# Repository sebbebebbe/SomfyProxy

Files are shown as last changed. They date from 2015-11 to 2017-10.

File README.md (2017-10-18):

SomfyProxy

This is a project for controlling your Somfy blinds with a Tellstick .NET.

You are going to need:
- Raspberry Pi with node.js
- Arduino with a 433Mhz reciever module

There is a more detailed information about the circuitry in the fritzing file.

Cable to Somfy remote

1(redish color): 3,3V
2:GND
3:Stop
4:Up
5:Down
6:Select
7: CH1
8: CH2
9: CH3
10:CH4

Pins on Raspberry Pi:

function	PhysicalPIN	wPi
up		18		1
down		24		5
stop		14		15
select ch	23		4

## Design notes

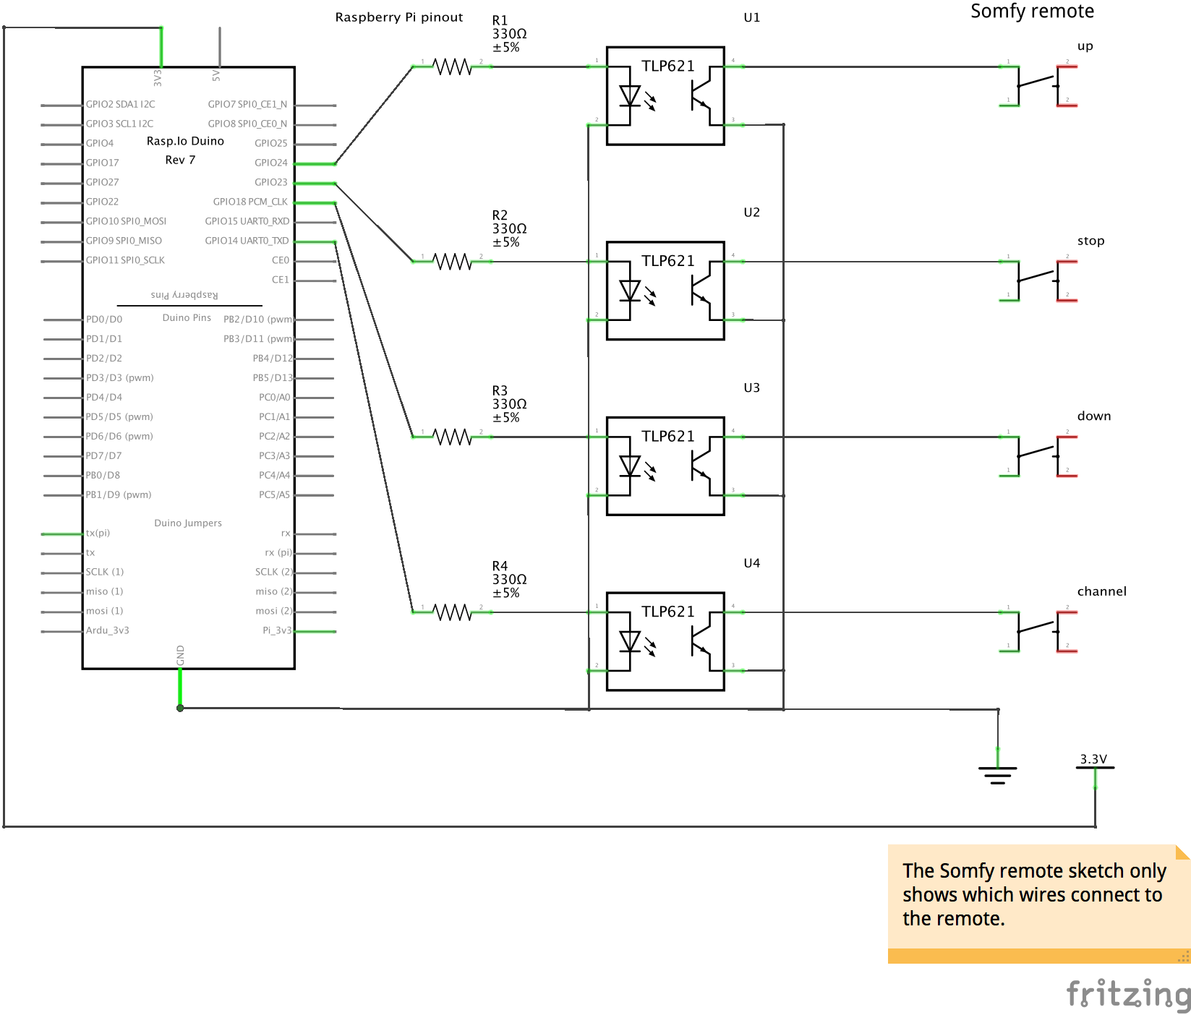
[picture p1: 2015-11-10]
SomfyProxy schematics.png

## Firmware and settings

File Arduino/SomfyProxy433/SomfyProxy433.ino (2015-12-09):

/*
SomfyProxy433

Inspired from examples @ http://code.google.com/p/rc-switch/

 DATA PIN needs to be connected to Digital input #3
 VCC PIN into 5V on Arduino
 GND PIN into ground on same side as 5V VCC
 */

#include <RCSwitch.h>
RCSwitch mySwitch = RCSwitch();

#define DATA_PIN 3

void setup() {

 pinMode(DATA_PIN, INPUT);
 
 Serial.begin(9600);
 mySwitch.enableReceive(1);  // Receiver on interrupt 1 => that is pin D3
 Serial.println("SomfyProxy433 started");
}

static unsigned long count = 0;

void loop() {
 
 if (mySwitch.available()) {
   
   int value = mySwitch.getReceivedValue();
   
   if (value == 0) {
     Serial.print("Unknown encoding");
   } 
   else {
     outputPayload(mySwitch.getReceivedValue(), mySwitch.getReceivedBitlength(), mySwitch.getReceivedDelay(), mySwitch.getReceivedRawdata(),mySwitch.getReceivedProtocol());
   }
   
   mySwitch.resetAvailable();    
   count = 0;
 }
}

void outputPayload(unsigned long decimal, unsigned int length, unsigned int delay, unsigned int* raw, unsigned int protocol) {

  if (decimal == 0) {
    Serial.print("Unknown encoding.");
  } else {
    Serial.print("payload;");
    char* b = dec2binWzerofill(decimal, length);
    //Decimal value
    Serial.print(decimal);
    Serial.print(";");
    //bitlength
    Serial.print( length );
    Serial.print(";");
    //binary
    Serial.print( b );
    Serial.print(";");
    //tri-state
    Serial.print( bin2tristate( b) );
    Serial.print(";");
    //pulse length microseconds
    Serial.print(delay);
    Serial.print(";");
    //protocol
    Serial.println(protocol);
  }
  
  Serial.print("Raw data: ");
  for (int i=0; i<= length*2; i++) {
    Serial.print(raw[i]);
    Serial.print(",");
  }
  Serial.println();
  Serial.println();
}


char* bin2tristate(char* bin) {
  char returnValue[50];
  int pos = 0;
  int pos2 = 0;
  while (bin[pos]!='\0' && bin[pos+1]!='\0') {
    if (bin[pos]=='0' && bin[pos+1]=='0') {
      returnValue[pos2] = '0';
    } else if (bin[pos]=='1' && bin[pos+1]=='1') {
      returnValue[pos2] = '1';
    } else if (bin[pos]=='0' && bin[pos+1]=='1') {
      returnValue[pos2] = 'F';
    } else {
      return "not applicable";
    }
    pos = pos+2;
    pos2++;
  }
  returnValue[pos2] = '\0';
  return returnValue;
}

char * dec2binWzerofill(unsigned long Dec, unsigned int bitLength){
  static char bin[64]; 
  unsigned int i=0;

  while (Dec > 0) {
    bin[32+i++] = (Dec & 1 > 0) ? '1' : '0';
    Dec = Dec >> 1;
  }

  for (unsigned int j = 0; j< bitLength; j++) {
    if (j >= bitLength - i) {
      bin[j] = bin[ 31 + i - (j - (bitLength - i)) ];
    }else {
      bin[j] = '0';
    }
  }
  bin[bitLength] = '\0';
  
  return bin;
}

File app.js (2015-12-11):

var express = require('express');
var app = express();
var serialport = require("serialport");
var SerialPort = serialport.SerialPort;

var sleep = require('sleep');

var Gpio = require('onoff').Gpio,
  upButton = new Gpio(18, 'out'),
  downButton = new Gpio(24, 'out'),
  stopButton = new Gpio(14, 'out'),
  selectButton = new Gpio(23, 'out')

var standardButtonPress = 60000; //microseconds

var serialPort = new SerialPort("/dev/ttyUSB1", {
	baudrate: 9600,
	parser: serialport.parsers.readline("\n")
});

serialPort.on("open", function () {
	console.log('serial port open');
	serialPort.on('data', function (data) {
		console.log(data);
		var parameters = data.split(';')

		//these values are based on what i get from my Tellstick
		if(parameters[1] == '192')
		{
			up();
		}

		if(parameters[1] == '3')
		{
			down();
		}

		if(parameters[1] == '48')
		{
			stop();
		}

	});
});

app.get('/', function(req, res) {
  	res.type('text/plain');
  	res.send('');
});

app.post('/up', function(req, res) {
	res.type('text/plain');
  	res.send('going up');

	up();
});

app.post('/down', function(req, res) {
  	res.type('text/plain');
  	res.send('going down');

	down();

});

app.post('/stop', function(req, res) {
  	res.type('text/plain');
  	res.send('stopping');

	stop();

});

app.post('/select', function(req, res) {
  	res.type('text/plain');
  	res.send('changed channel');

	selectChannel();
});

function up() {
	upButton.writeSync(1);
	sleep.usleep(standardButtonPress);
	upButton.writeSync(0);
}

function stop() {
	stopButton.writeSync(1);
	sleep.usleep(standardButtonPress);
	stopButton.writeSync(0);
}

function down() {
	downButton.writeSync(1);
	sleep.usleep(standardButtonPress);
	downButton.writeSync(0);
}

function selectChannel()
{
	selectButton.writeSync(1);
	sleep.sleep(2);
	selectButton.writeSync(0);
}

app.listen(4747);

function exit() {
  	stopButton.writeSync(0);
  	stopButton.unexport();

  	upButton.writeSync(0);
  	upButton.unexport();

  	downButton.writeSync(0);
  	downButton.unexport();

  	selectButton.writeSync(0);
  	selectButton.unexport();

  	process.exit();
}

process.on('SIGINT', exit);

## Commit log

2015-09-09 added some notes about pin setup
2015-11-10 Added schematics for the hardware
    [SomfyProxy schematics.fzz]
2015-12-09 added code to connect with Arduino over serial
2015-12-11 changed my mind about the resets and adjusted gpio init
    [app.js]
